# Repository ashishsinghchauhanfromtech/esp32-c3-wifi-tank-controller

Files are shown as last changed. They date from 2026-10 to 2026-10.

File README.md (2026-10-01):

# ESP32-C3 WiFi Tank Controller

### A 3D-Printed Robotics Prototype

A custom-built tank prototype combining **mechanical design, FDM 3D printing, embedded electronics, and wireless browser-based control**.

## Project Overview

The goal of this project was to design, manufacture, assemble, and control a compact motorized vehicle.

The mechanical structure includes a custom chassis, gears, wheels, belt components, and motor mounts designed using **Tinkercad** and fabricated using **FDM 3D printing**.

An **ESP32-C3 microcontroller** hosts a mobile-friendly control interface over its own Wi-Fi network, allowing independent control of two DC motors without requiring internet access.

---

## Mechanical Design & Manufacturing

* **CAD Software:** Tinkercad
* **Manufacturing Method:** FDM 3D Printing
* **Printer:** Creality Ender 3
* **Material:** PLA+
* **Nozzle:** 0.4 mm
* **Slicer:** Ultimaker Cura

### Custom-Designed Components

* **Chassis:** Structural platform for the vehicle.
* **Gears:** Mechanical transmission components.
* **Wheels:** Drive and ground-contact components.
* **Belt Components:** Experimental belt mechanism.
* **Motor Mounts:** Support and positioning for drive motors.
* **Electronic Cover:** Protective structure for electronics.
* **Charging/USB Mounts:** Access for charging and programming.

### Design-to-Prototype Workflow

1. Developed the mechanical components in Tinkercad.
2. Exported the models as STL files.
3. Prepared the parts for 3D printing using Ultimaker Cura.
4. Printed the components using a Creality Ender 3.
5. Assembled the printed mechanical components.
6. Integrated the motors, motor driver, battery system, and ESP32-C3.
7. Tested the assembled prototype and refined the design where required.

---

## Prototype Gallery

### 1. Assembled Tank Prototype

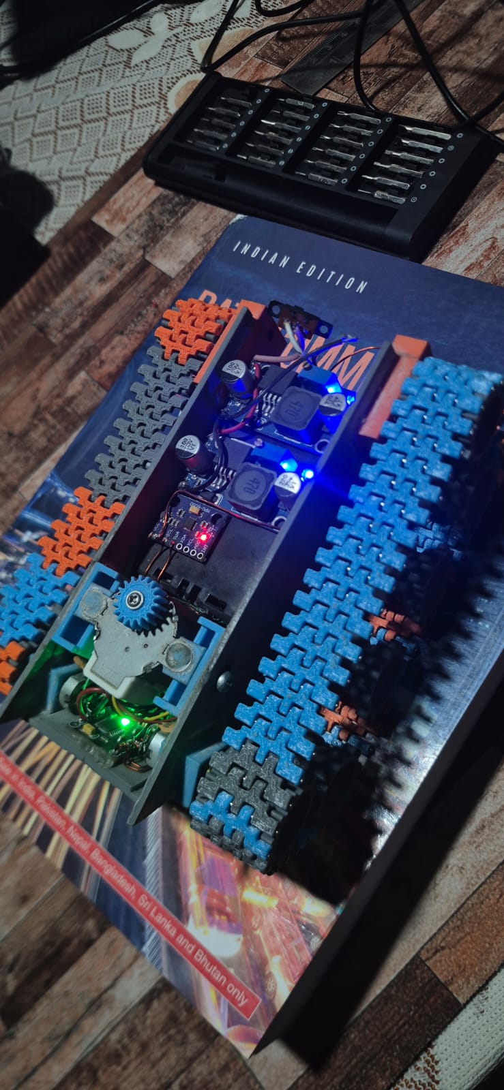
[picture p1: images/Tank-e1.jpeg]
Assembled tank prototype


### 2. Chassis Development

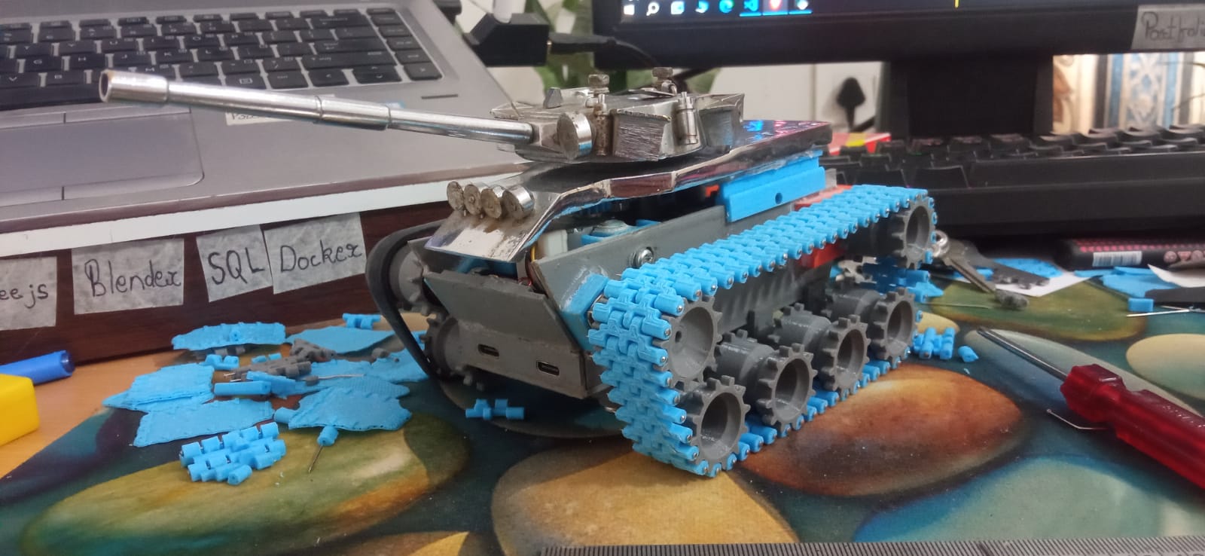
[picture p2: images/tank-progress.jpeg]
Chassis development


### 3. Electronics and Wiring

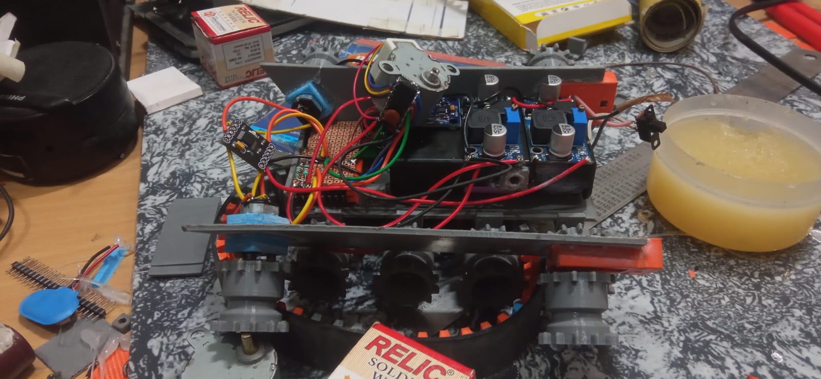
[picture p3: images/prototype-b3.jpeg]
Electronics and wiring


### 4. Mechanical Assembly

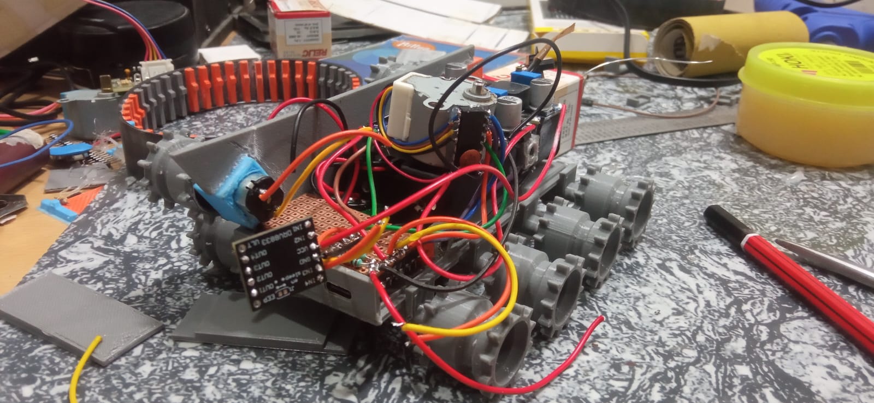
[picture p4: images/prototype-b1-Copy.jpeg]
Mechanical assembly


### 5. Prototype Development

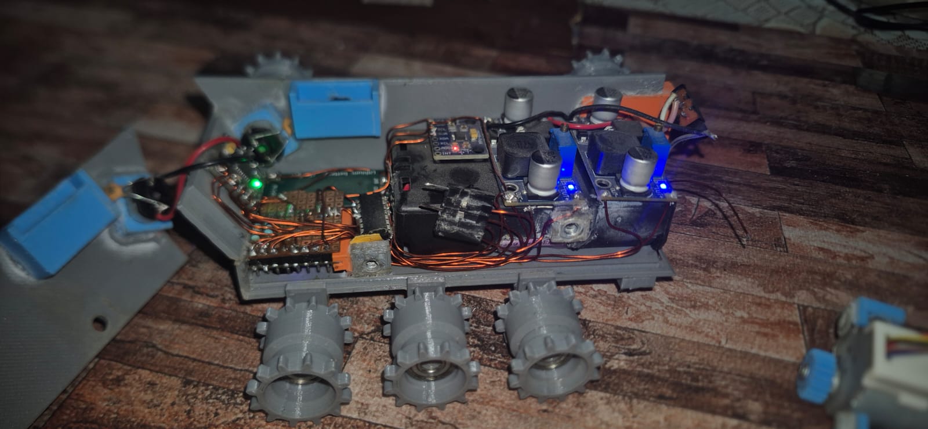
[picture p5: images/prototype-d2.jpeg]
Prototype development


### 6. Motor and Gear System

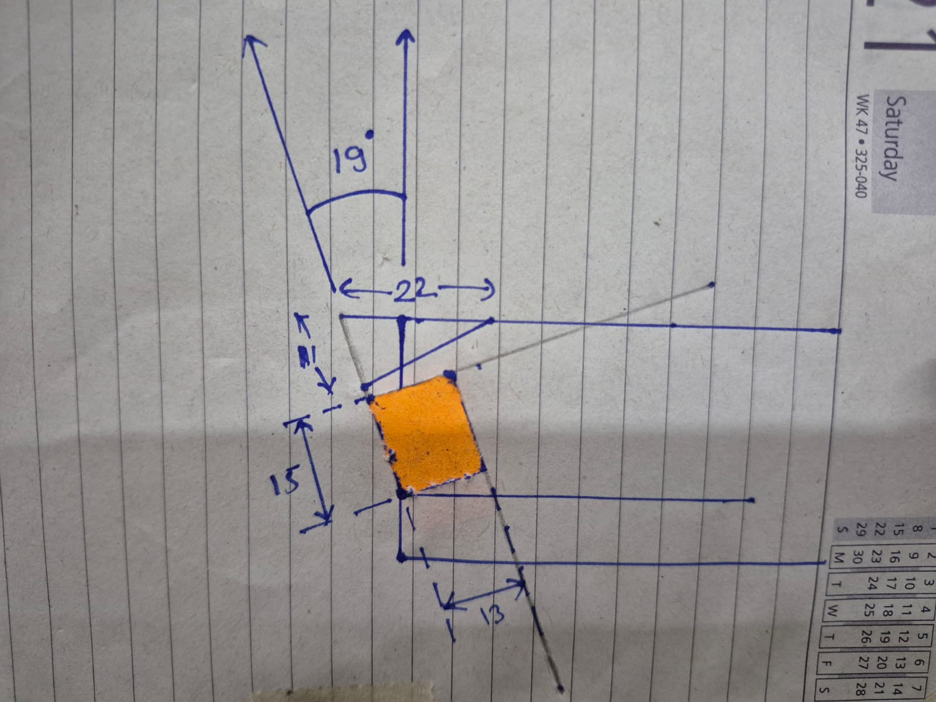
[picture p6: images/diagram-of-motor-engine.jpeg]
Motor and gear system


### Chassis and Wheel Development

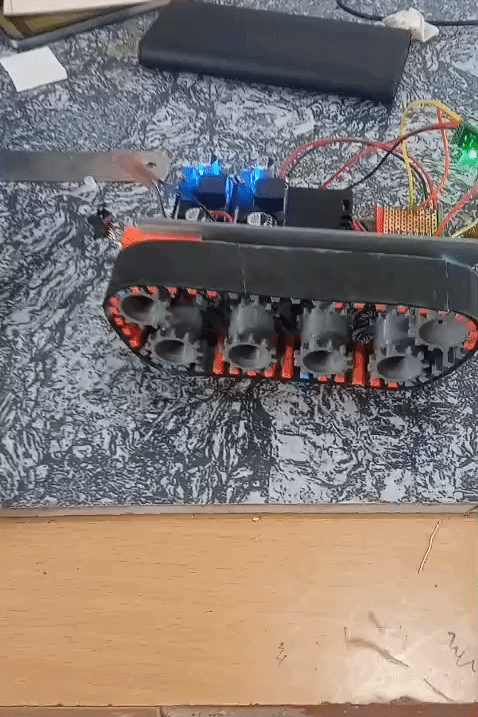
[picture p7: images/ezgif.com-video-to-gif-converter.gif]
Chassis and Wheel Development


### 8. 3D-Printed Wheel

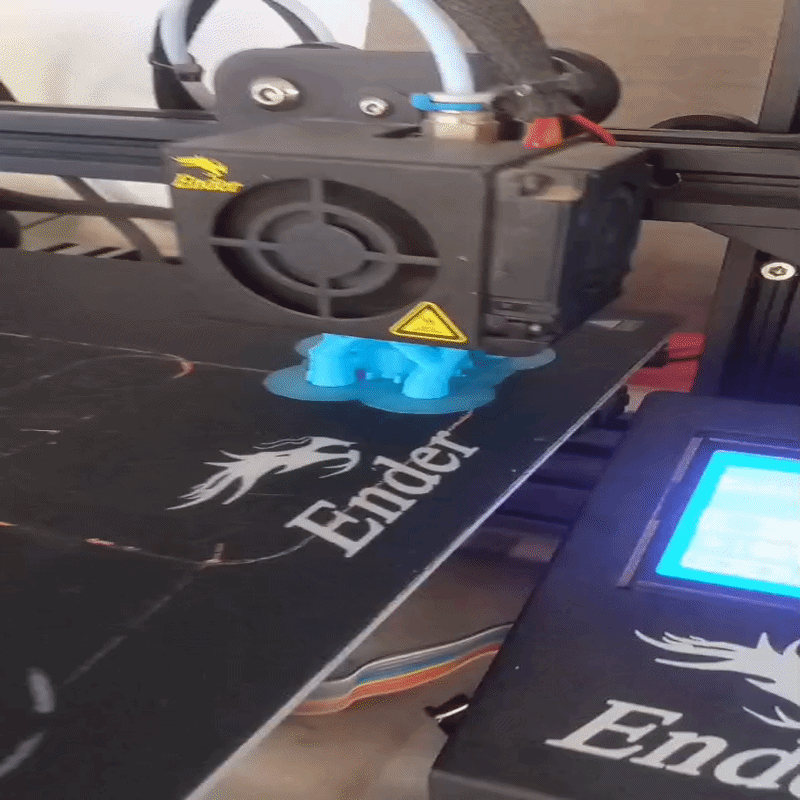
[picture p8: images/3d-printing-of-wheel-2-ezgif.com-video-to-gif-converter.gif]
3D printed wheel


### 9. Belt Prototype

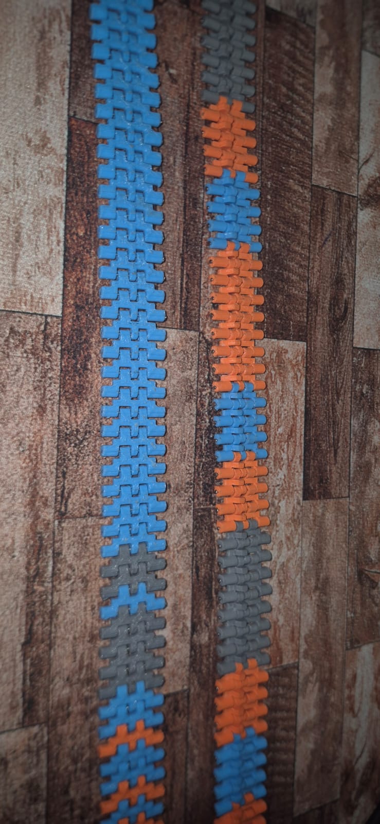
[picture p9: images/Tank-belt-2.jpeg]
Belt prototype


### 10. Wheel Prototype

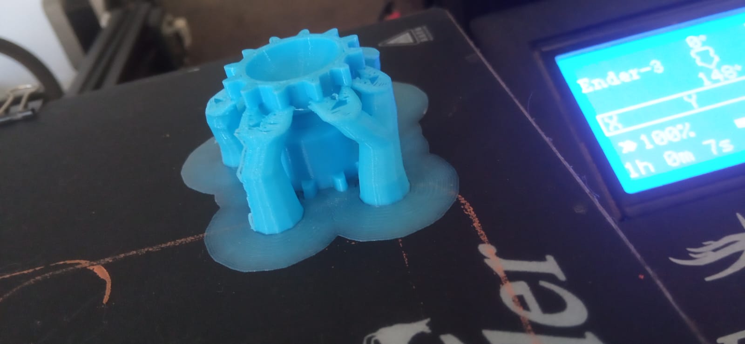
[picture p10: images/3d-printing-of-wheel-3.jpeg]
Wheel prototype


---

## Electronics & Control

### Main Components

* ESP32-C3 Development Board
* DRV8833 Dual Motor Driver
* Two DC Gear Motors
* Battery System
* Voltage Regulation
* Wi-Fi Access Point
* LittleFS Storage

### Motor Control Features

* Independent left and right motor control
* Variable motor speed using PWM
* Forward and reverse movement
* Automatic motor stop
* Automatic control centering
* Wireless operation without internet access

---

## Software

* Arduino / C++
* HTML
* CSS
* JavaScript
* PWM Motor Control
* ESP32-C3 Wi-Fi Access Point
* LittleFS

The web interface is stored on the ESP32-C3 using LittleFS, allowing the controller to operate without an external web server or internet connection.

---

## How It Works

1. The ESP32-C3 creates its own Wi-Fi network.
2. A phone or laptop connects to the ESP32-C3 network.
3. The user opens the controller webpage in a browser.
4. The webpage is served directly from the ESP32-C3.
5. Two independent controls operate the motors.
6. Motor speed changes according to the control position.
7. Releasing the controls stops the motors and returns the controls to neutral.

### System Architecture

```text
Phone / Laptop
       |
       | Wi-Fi
       v
 ESP32-C3 Access Point
       |
       +-- LittleFS Web Interface
       |
       v
   Motor Control
       |
       v
   DRV8833 Driver
      /       \
     v         v
  Motor A   Motor B
```

---

## Mechanical Design Considerations

The project involved several practical mechanical challenges during development, including:

* Gear fit and tolerance
* Gear durability
* Motor alignment
* Printed-part assembly
* Belt tension
* Wheel alignment
* Support removal
* Mechanical packaging
* Integration of electronics with the printed chassis

Some printed components required redesign and iteration to improve fit, strength, and assembly.

### 3D Printing Observations

During development, several practical printing issues were encountered:

* A gear fractured during support removal while the teeth remained intact.
* Some gear interfaces required tolerance adjustments.
* Stringing and warping were observed during some prints.
* Motor mount alignment required attention during assembly.
* Belt components required experimentation to achieve suitable tension.

These observations helped guide subsequent design iterations.

---

## 3D Models — STL Files

The following links point to 3D model files stored in this repository. They can be downloaded and opened using Cura, Tinkercad, or compatible 3D modeling software.

### Wheels and Gears

* [Ground Contact Gear Wheel — STL](https://github.com/ashishsinghchauhanfromtech/esp32-c3-wifi-tank-controller/blob/main/mechanical-design/GearWeels1-That-touches-the-ground-1-of-10-Total%5B12%5D.stl)

### Belt Components

* [Belt Prototype 1 — STL](https://github.com/ashishsinghchauhanfromtech/esp32-c3-wifi-tank-controller/blob/main/mechanical-design/belt-prototype-1.stl)
* [Belt Prototype 2 — STL](https://github.com/ashishsinghchauhanfromtech/esp32-c3-wifi-tank-controller/blob/main/mechanical-design/belt-prototype-2.stl)
* [Belt Tightening Wheel Gear Mount Mechanism — STL](https://github.com/ashishsinghchauhanfromtech/esp32-c3-wifi-tank-controller/blob/main/mechanical-design/Belt-tightning-wheel-gear-mount-mechanism.stl)

### Chassis Components

* [Chassis Top Electronic Safety — STL](https://github.com/ashishsinghchauhanfromtech/esp32-c3-wifi-tank-controller/blob/main/mechanical-design/Chassis-top-electronic-safety.stl)
* [Chassis Base with USB and Charging Indicator — STL](https://github.com/ashishsinghchauhanfromtech/esp32-c3-wifi-tank-controller/blob/main/mechanical-design/Chassis-Base-parallel-to-ground-with-usb-and-charging-indicat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)

### Charging and Programming

* [Type-C Ports for Charging and Code Uploading — STL](https://github.com/ashishsinghchauhanfromtech/esp32-c3-wifi-tank-controller/blob/main/mechanical-design/Type-c-Ports-for-charging-and-code-uploading.stl)

---

## Project Structure

```text
esp32-c3-wifi-tank-controller/
|
|-- README.md
|-- LICENSE
|
|-- firmware/
|   |-- tank.ino
|
|-- web-interface/
|   |-- index.html
|   |-- style.css
|   |-- js.js
|
|-- mechanical-design/
|   |-- *.stl
|   |-- 3d-printing-notes.md
|
|-- images/
|   |-- Tank-e1.jpeg
|   |-- tank-progress.jpg
|   |-- prototype-b3.jpg
|   |-- prototype-b1-Copy.jpg
|   |-- prototype-d2.jpg
|   |-- diagram-of-motor-engine.jpg
|   |-- prototype-c1.jpg
|   |-- 3d-printing-of-wheel-2.jpg
|   |-- Tank-belt-2.jpg
|   |-- 3d-printing-of-wheel-3.jpg
|
|-- hardware/
    |-- hardware documentation
```

---

## Project Status

**Functional prototype**

The project includes:

* 3D-printed mechanical components
* Custom Tinkercad designs
* Two DC motors
* DRV8833 motor driver
* ESP32-C3 wireless control
* Browser-based control interface
* Local Wi-Fi operation
* LittleFS-hosted web interface
* STL files for mechanical components

---

## Future Improvements

Potential future improvements include:

* Improved gear durability
* Optimized gear tolerances
* Improved belt mechanism
* More compact electronics mounting
* Improved motor alignment
* Reduced 3D-printing material usage
* Further chassis weight optimization
* Additional mechanical iterations

---

## License

The software and firmware in this project are released under the **MIT License**.

See the [LICENSE](LICENSE) file for details.

The 3D models and mechanical design files are included in the repository for reference and further development.

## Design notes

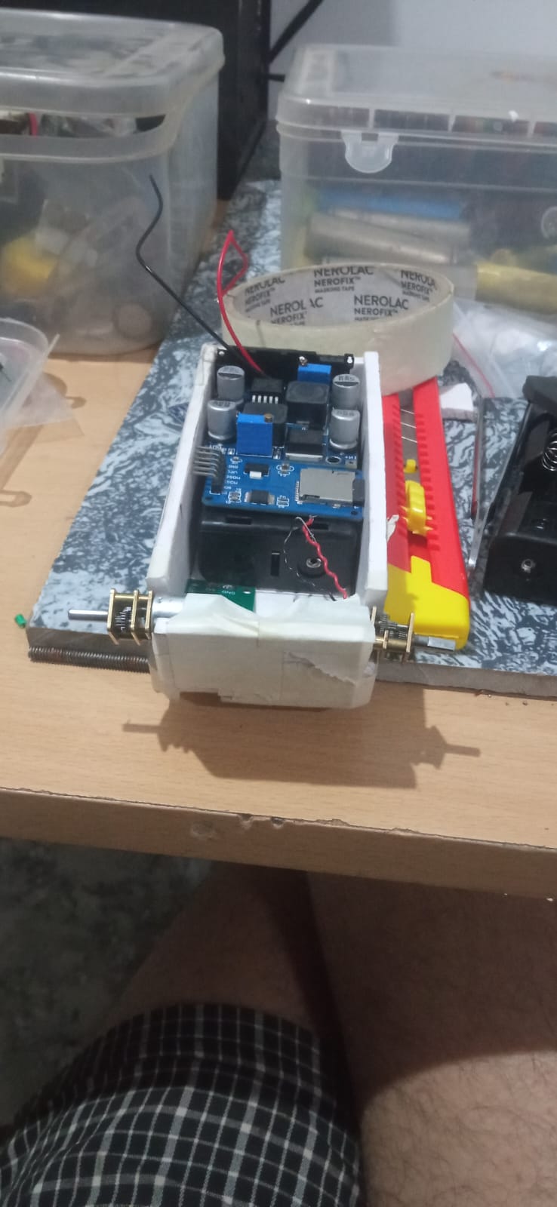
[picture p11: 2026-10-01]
images/prototype-a4.jpeg

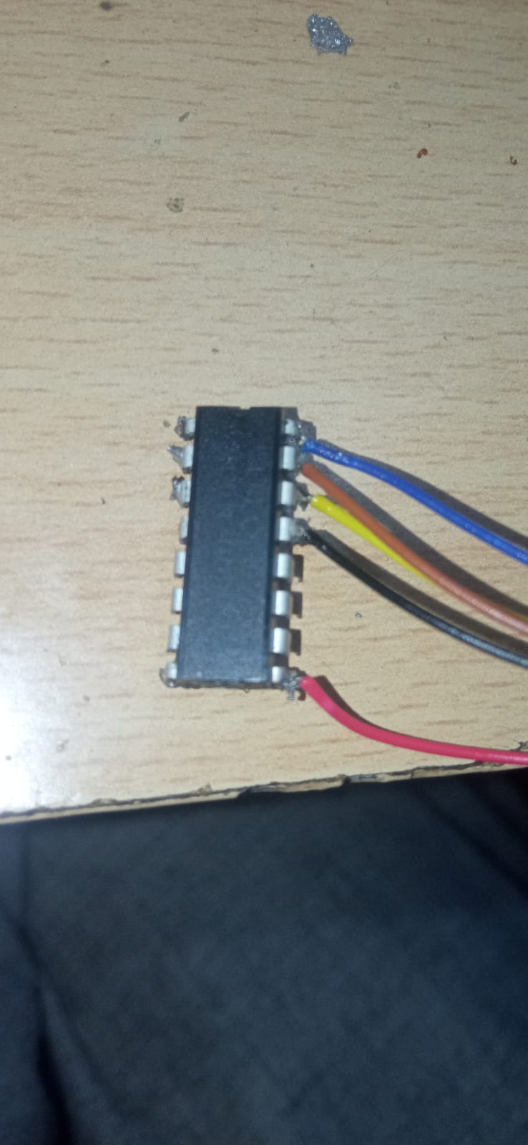
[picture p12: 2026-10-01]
images/ULN2003-Stapper-motor-driver-Copy.jpeg

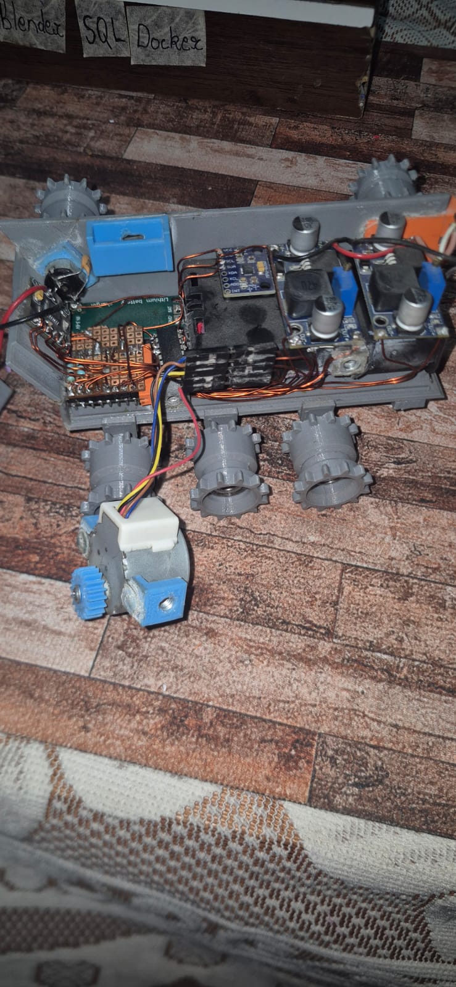
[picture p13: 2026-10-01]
images/Prototype-d6.jpeg

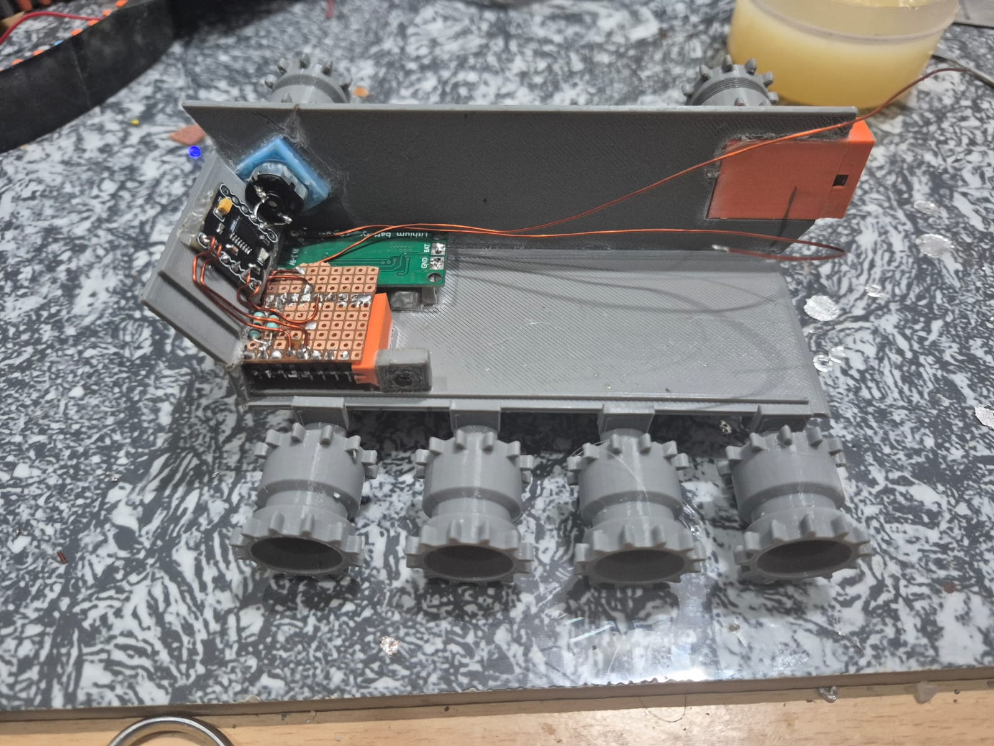
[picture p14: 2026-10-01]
images/motor-with-esp-Copy.jpeg

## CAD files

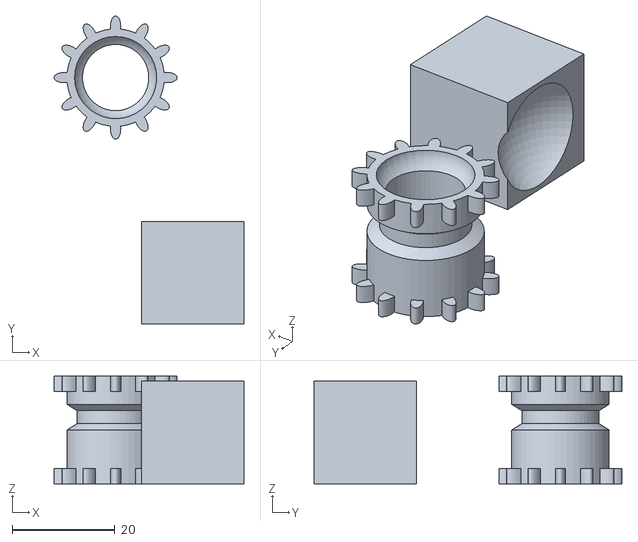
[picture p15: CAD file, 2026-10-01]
mechanical-design/GearWeels1-That-touches-the-ground-1-of-10-Total[12].stl
37.0 x 60.0 x 21.0

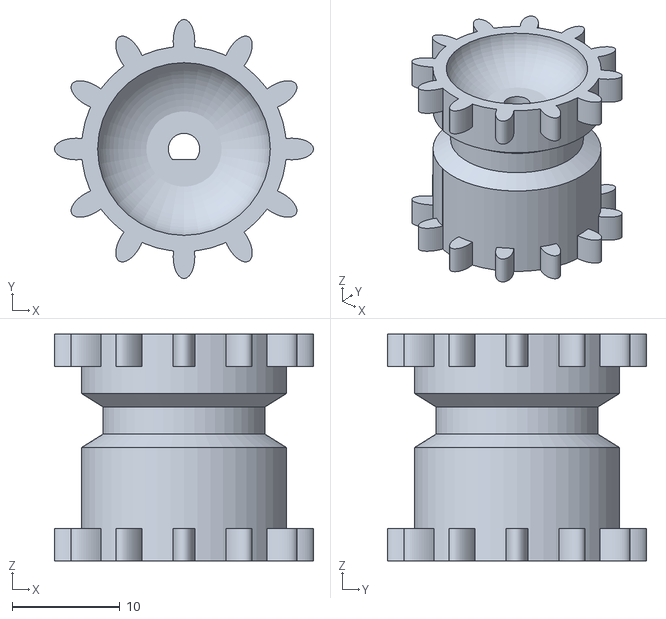
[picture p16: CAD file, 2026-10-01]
mechanical-design/GearWeels2-Connected-to-engine-1-of-2-total[12].stl
24.0 x 24.0 x 21.0

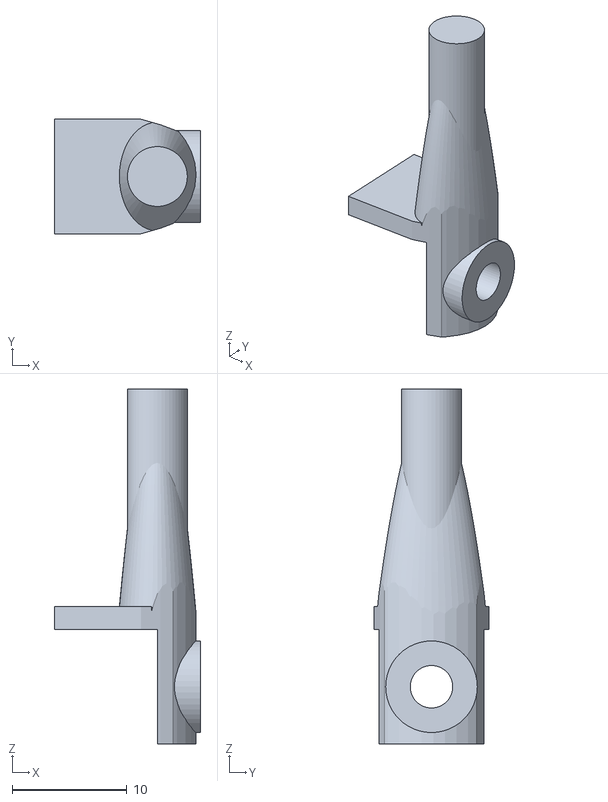
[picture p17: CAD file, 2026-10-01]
mechanical-design/connector-for-ground-wheels-to-the-chassis.stl
12.8 x 10.0 x 31.0

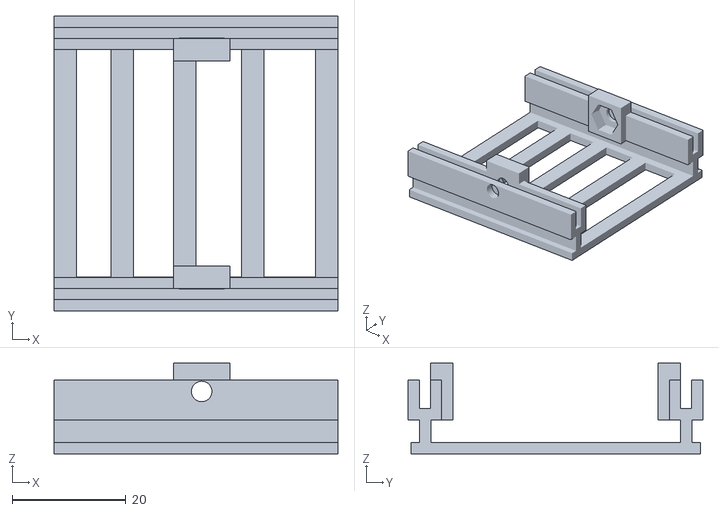
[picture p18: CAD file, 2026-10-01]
mechanical-design/Chassis-top-electronic-safety.stl
50.0 x 51.9 x 16.0

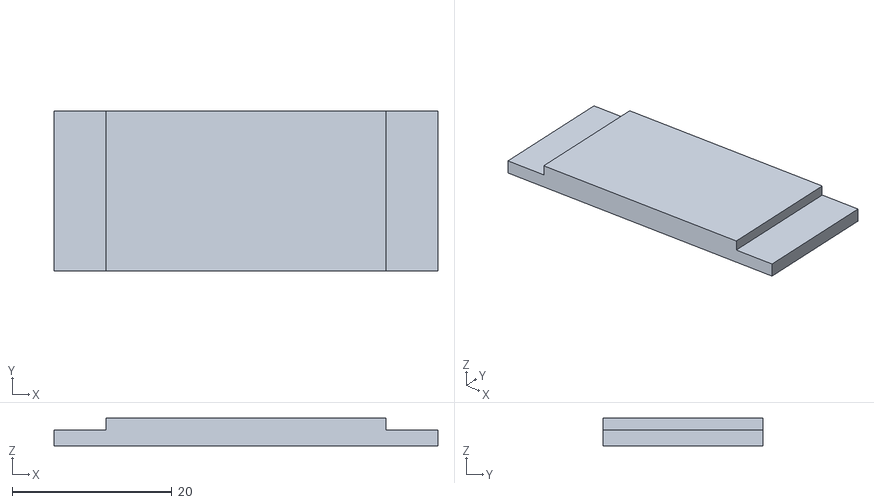
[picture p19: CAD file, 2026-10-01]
mechanical-design/Chassis-front-profile.stl
48.0 x 20.0 x 3.50

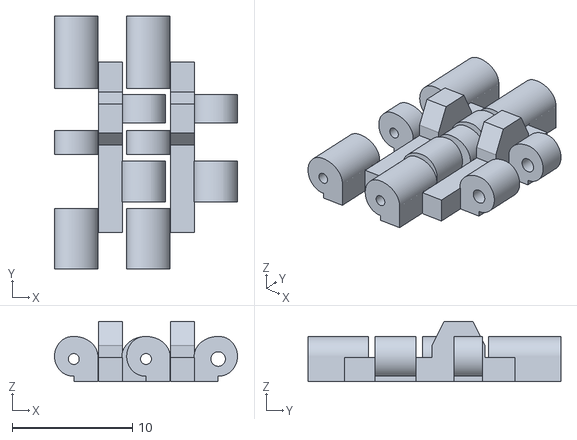
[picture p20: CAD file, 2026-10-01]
mechanical-design/belt-prototype-2.stl
15.2 x 21.0 x 5.00

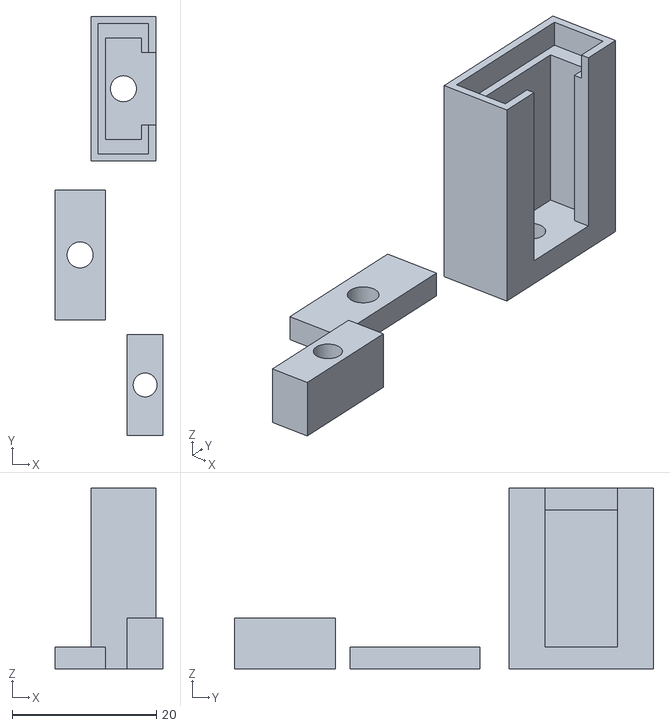
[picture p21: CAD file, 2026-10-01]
mechanical-design/Belt-tightning-wheel-gear-mount-mechanism.stl
15.0 x 58.0 x 25.0

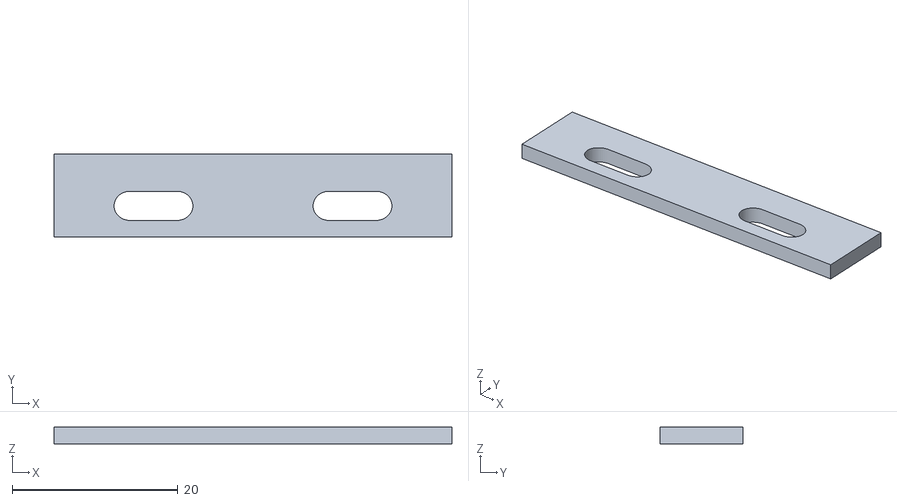
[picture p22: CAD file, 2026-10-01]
mechanical-design/Type-c-Ports-for-charging-and-code-uploading.stl
48.0 x 10.0 x 2.00

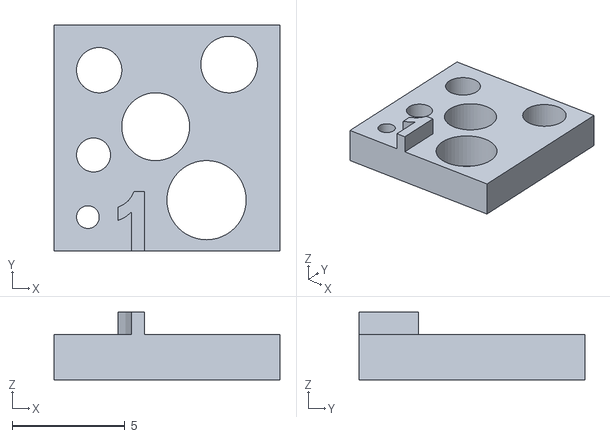
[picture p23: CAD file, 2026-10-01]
mechanical-design/for-belt-mearurement.stl
10.0 x 10.0 x 3.00

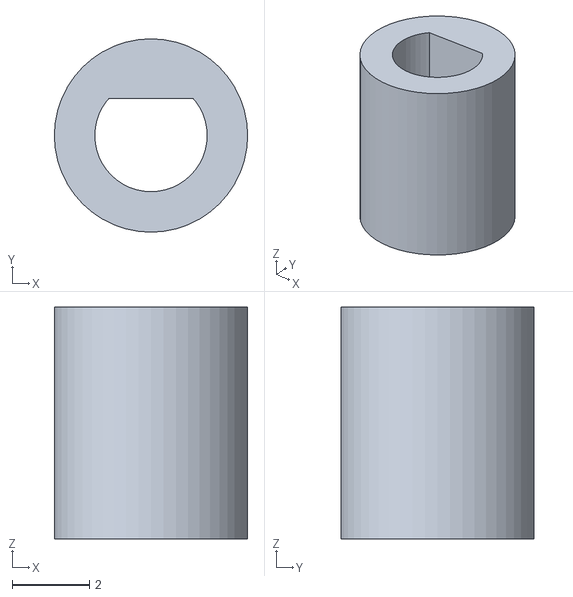
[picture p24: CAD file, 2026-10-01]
mechanical-design/Engine-motor-shaft-measurement.stl
5.00 x 5.00 x 6.00

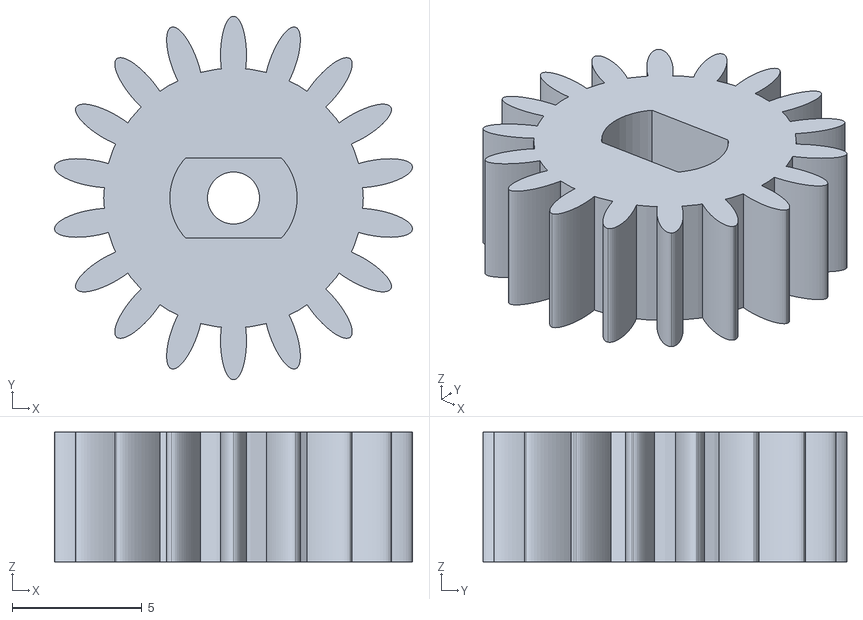
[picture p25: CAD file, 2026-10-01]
mechanical-design/tank-nozel-motor-gear1.stl
13.8 x 14.0 x 5.00

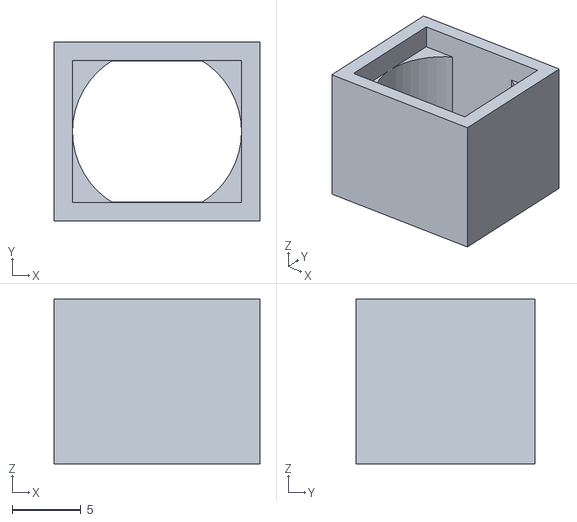
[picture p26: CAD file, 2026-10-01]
mechanical-design/Engine-motor-lower-mount.stl
15.0 x 13.0 x 12.0

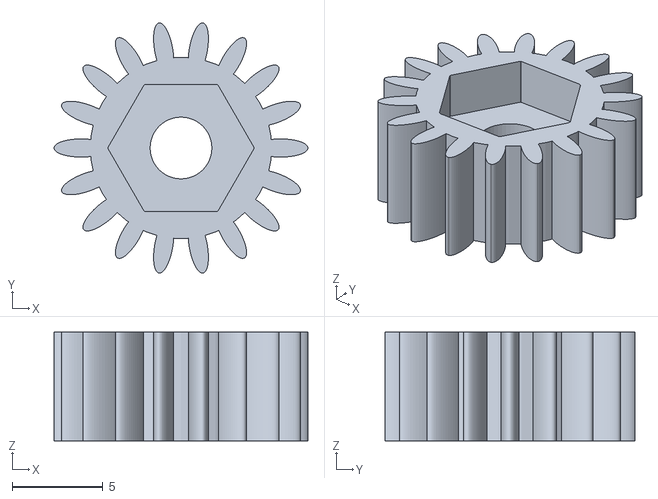
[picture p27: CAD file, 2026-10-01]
mechanical-design/tank-nozel-motor-gear2.stl
14.0 x 13.8 x 6.00

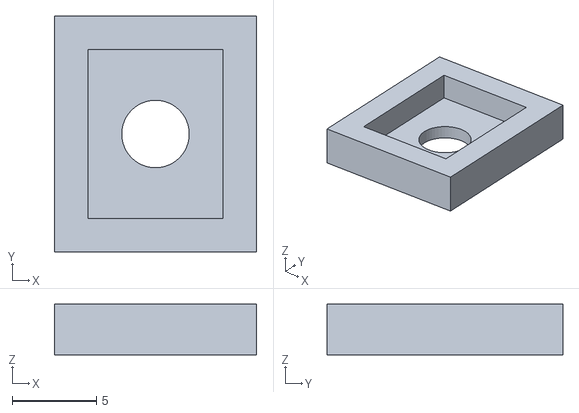
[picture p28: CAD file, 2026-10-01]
mechanical-design/Engine-motor-top-mount.stl
12.0 x 14.0 x 3.00

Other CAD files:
mechanical-design/tank-nozel-motor-top-mount.stl
mechanical-design/Chassis-Base-parallel-to-ground-with-usb-and-charging-indicator.stl
mechanical-design/esp32-c3-mount.stl
mechanical-design/Chassis-side-profile-for-belttightningwheels-groundwheels-enginewheels.stl
mechanical-design/Tank-nozel-motor-mount-on-top.stl
mechanical-design/belt-prototype-1.stl

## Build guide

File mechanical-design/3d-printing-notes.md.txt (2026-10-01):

# 3D Printing & Manufacturing Notes

## Project
**ESP32-C3 WiFi Tank Controller — Mechanical Prototype**

## 1. Manufacturing Overview

The mechanical components of this tank prototype were designed in Tinkercad and fabricated using FDM (Fused Deposition Modeling) 3D printing.

The printed components include:
- Chassis
- Gears
- Motor mounts

The objective was to create a functional mechanical structure capable of supporting the drive system and integrating with the electronic control hardware.

## 2. Equipment and Materials

| Parameter | Specification |
|---|---|
| 3D Printer | Creality Ender 3 |
| Slicing Software | Ultimaker Cura |
| Printing Technology | FDM / FFF |
| Material | PLA+ |
| Nozzle Diameter | 0.4 mm |
| Layer Height | Not specified |
| Infill Density | 100% |
| Wall Settings | Not specified |
| CAD Software | Tinkercad |
| Export Format | STL |

*Note: Layer height and wall settings are unspecified because the exact values have not been confirmed.*

## 3. Design-to-Manufacturing Workflow

### Step 1 — CAD Modeling
Created the chassis, gears, and motor mounts using Tinkercad. The models were intended to provide structural support, motor mounting, and mechanical drive functionality.

### Step 2 — STL Export
Exported the designed components into STL format for preparation in the slicing software.

### Step 3 — Slicing and Print Preparation
Imported the STL models into Ultimaker Cura and prepared the components for fabrication on the Creality Ender 3.

The confirmed infill density was 100%. Other slicing parameters, including layer height and wall settings, have not been documented.

### Step 4 — Fabrication
Manufactured the mechanical components using PLA+ filament and FDM 3D printing.

### Step 5 — Assembly and Integration
Assembled the printed chassis, gears, and motor mounts as part of the tank prototype. The mechanical structure was integrated with the DC motors and electronic control system.

### Step 6 — Fit and Functional Evaluation
Evaluated the printed components during assembly and prototype testing. Several issues were identified, as documented below.

## 4. Printing and Assembly Observations

### Gear Fracture During Support Removal
A gear fractured at its central region during support removal, while its teeth remained intact.

**Observation:** The component was vulnerable during post-processing.

**Potential areas for investigation:**
- Hub geometry and surrounding wall thickness
- Support placement and removal technique
- Part orientation during printing
- Material behavior and local stress concentration

**Possible future improvements:** Review the hub geometry, adjust support placement, and evaluate alternative orientations or stronger local geometry.

### Gear Fit and Tolerance
Gear engagement and fit presented tightness or looseness issues.

**Observation:** The fit between mating components required attention during assembly.

**Potential areas for investigation:**
- Gear dimensions and center distance
- Shaft and bore dimensions
- Manufacturing tolerances
- Printer dimensional accuracy

**Possible future improvements:** Use small test prints to evaluate clearances before manufacturing the complete set of components.

### Stringing or Warping
Stringing or warping was observed during printing.

**Potential areas for investigation:**
- Retraction settings
- Nozzle and bed temperatures
- Bed adhesion
- Cooling settings
- Filament condition and storage

**Possible future improvements:** Calibrate retraction, verify material-specific temperature recommendations, and review bed preparation and first-layer adhesion.

### Motor Mount Alignment
Motor mounting alignment presented an issue during assembly.

**Observation:** The relationship between the mounting geometry and the motor position required attention.

**Potential areas for investigation:**
- Mounting-hole dimensions
- Motor seating surfaces
- Shaft alignment
- Clearance between the motor, gears, and chassis

**Possible future improvements:** Refine mounting geometry and validate alignment using a small test print before printing revised full-size parts.

*The potential causes and improvements listed above are design considerations for future iterations, not confirmed root causes or completed modifications.*

## 5. Design Considerations for Future Iterations

Potential areas for refinement include:

- Improving gear hub strength and resistance to handling damage
- Refining gear clearances and shaft fit
- Improving motor mounting alignment
- Reducing printing defects through slicer calibration
- Reviewing support placement for easier post-processing
- Evaluating material usage and structural requirements
- Improving assembly access and maintainability

Any revised geometry or print settings should be validated through physical testing.

## 6. Documentation and Reproducibility

The project repository includes, or is intended to include:

- Tinkercad-designed component exports in STL format
- Prototype photographs
- ESP32-C3 firmware
- Browser-based motor control interface
- Hardware and assembly documentation

Exact layer height, wall settings, printing temperatures, print speeds, and support parameters have not been recorded in this document.

## 7. Project Outcome

The 3D-printed chassis, gears, and motor mounts form the mechanical structure of the ESP32-C3 WiFi Tank Controller prototype.

The fabrication and assembly process provided practical experience with CAD-to-STL preparation, FDM manufacturing, component fit, support removal, motor mounting, and mechanical integration with embedded electronics.

The identified issues provide concrete starting points for further design refinement and prototype testing.

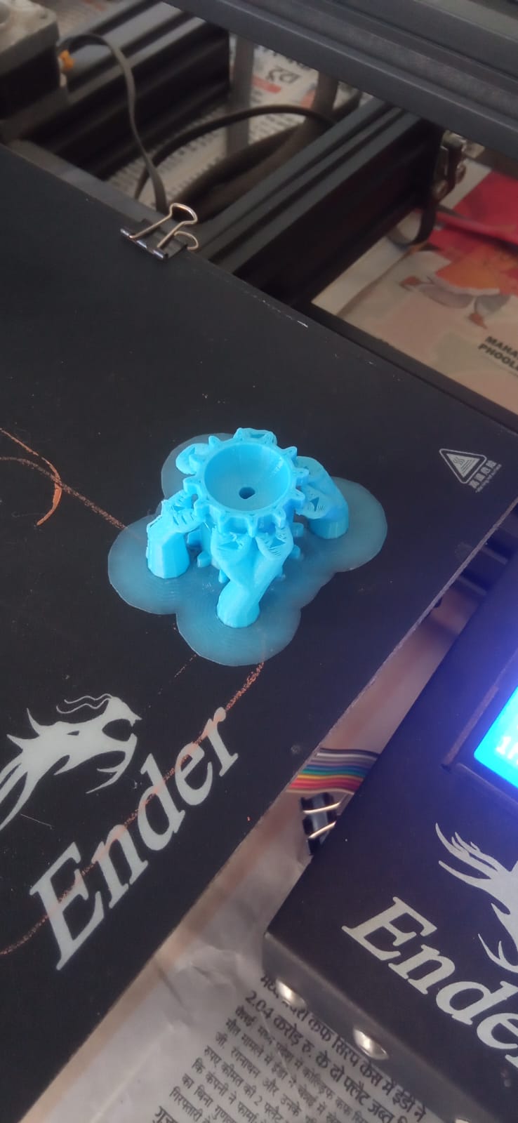
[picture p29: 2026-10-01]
images/3d-printing-of-wheel-4.jpeg

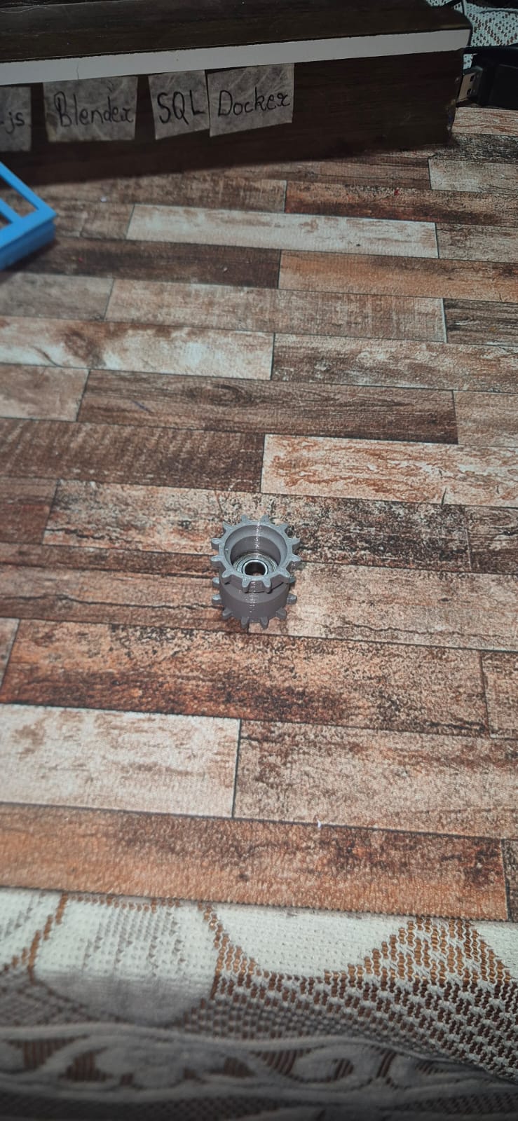
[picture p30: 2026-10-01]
images/printed-wheel.jpeg

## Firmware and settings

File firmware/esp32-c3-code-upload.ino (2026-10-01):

#include <WiFi.h>
#include <WebServer.h>
#include <LittleFS.h>


// ============ MOTOR PINS ============

#define AIN1 3
#define AIN2 4

#define BIN1 8
#define BIN2 9



// ============ PWM SETTINGS ============

#define PWM_FREQ 20000
#define PWM_RES 8

#define MIN_PWM 50



// ============ WIFI ============

const char* ssid = "  ";//Name of your esp32c3
const char* password = "";//Password of esp32c3


WebServer server(80);



// ============ FUNCTIONS ============

void motorAForward();
void motorAReverse();
void motorAStop();

void motorBForward();
void motorBReverse();
void motorBStop();

int mapSpeed(int s);



// ================= SETUP =================

void setup()
{

  Serial.begin(115200);

  delay(1000);



  // -------- LittleFS --------

  if(!LittleFS.begin())
  {
    Serial.println("LittleFS Failed");
    return;
  }

  Serial.println("LittleFS Ready");




  // -------- Motor pins --------

  pinMode(AIN1, OUTPUT);
  pinMode(AIN2, OUTPUT);

  pinMode(BIN1, OUTPUT);
  pinMode(BIN2, OUTPUT);



  digitalWrite(AIN1, LOW);
  digitalWrite(AIN2, LOW);

  digitalWrite(BIN1, LOW);
  digitalWrite(BIN2, LOW);



  // -------- ESP32-C3 PWM --------

  ledcAttach(
    AIN1,
    PWM_FREQ,
    PWM_RES
  );


  ledcAttach(
    AIN2,
    PWM_FREQ,
    PWM_RES
  );


  ledcAttach(
    BIN1,
    PWM_FREQ,
    PWM_RES
  );


  ledcAttach(
    BIN2,
    PWM_FREQ,
    PWM_RES
  );



  // -------- WiFi AP --------

  WiFi.mode(WIFI_AP);

  WiFi.softAP(
    ssid,
    password
  );


  Serial.println("WiFi Started");

  Serial.print("IP Address: ");

  Serial.println(
    WiFi.softAPIP()
  );




  // ============ MOTOR ROUTES ============


  server.on(
    "/a/fwd",
    motorAForward
  );


  server.on(
    "/a/rev",
    motorAReverse
  );


  server.on(
    "/a/stop",
    motorAStop
  );



  server.on(
    "/b/fwd",
    motorBForward
  );


  server.on(
    "/b/rev",
    motorBReverse
  );


  server.on(
    "/b/stop",
    motorBStop
  );




  // ============ WEBSITE ============


  server.on(
    "/",
    []()
    {
      File file =
      LittleFS.open(
        "/index.html",
        "r"
      );

      server.streamFile(
        file,
        "text/html"
      );

      file.close();
    }
  );



  server.on(
    "/style.css",
    []()
    {
      File file =
      LittleFS.open(
        "/style.css",
        "r"
      );

      server.streamFile(
        file,
        "text/css"
      );

      file.close();
    }
  );



  server.on(
    "/js.js",
    []()
    {
      File file =
      LittleFS.open(
        "/js.js",
        "r"
      );

      server.streamFile(
        file,
        "application/javascript"
      );

      file.close();
    }
  );



  server.begin();


  Serial.println("Server Started");

}



// ================= LOOP =================


void loop()
{
  server.handleClient();
}






// ================= SPEED MAP =================


int mapSpeed(int s)
{

  s = constrain(
    s,
    0,
    255
  );


  return map(
    s,
    0,
    255,
    MIN_PWM,
    255
  );

}







// ================= MOTOR A =================



void motorAForward()
{

  int s =
  mapSpeed(
    server.arg("s").toInt()
  );


  digitalWrite(
    AIN2,
    LOW
  );


  ledcWrite(
    AIN1,
    s
  );


  server.send(
    200,
    "text/plain",
    "A FORWARD"
  );

}





void motorAReverse()
{

  int s =
  mapSpeed(
    server.arg("s").toInt()
  );


  digitalWrite(
    AIN1,
    LOW
  );


  ledcWrite(
    AIN2,
    s
  );


  server.send(
    200,
    "text/plain",
    "A REVERSE"
  );

}





void motorAStop()
{

  ledcWrite(
    AIN1,
    0
  );


  ledcWrite(
    AIN2,
    0
  );


  digitalWrite(
    AIN1,
    LOW
  );


  digitalWrite(
    AIN2,
    LOW
  );


  server.send(
    200,
    "text/plain",
    "A STOP"
  );

}








// ================= MOTOR B =================



void motorBForward()
{

  int s =
  mapSpeed(
    server.arg("s").toInt()
  );


  digitalWrite(
    BIN2,
    LOW
  );


  ledcWrite(
    BIN1,
    s
  );


  server.send(
    200,
    "text/plain",
    "B FORWARD"
  );

}





void motorBReverse()
{

  int s =
  mapSpeed(
    server.arg("s").toInt()
  );


  digitalWrite(
    BIN1,
    LOW
  );


  ledcWrite(
    BIN2,
    s
  );


  server.send(
    200,
    "text/plain",
    "B REVERSE"
  );

}





void motorBStop()
{

  ledcWrite(
    BIN1,
    0
  );


  ledcWrite(
    BIN2,
    0
  );


  digitalWrite(
    BIN1,
    LOW
  );


  digitalWrite(
    BIN2,
    LOW
  );


  server.send(
    200,
    "text/plain",
    "B STOP"
  );

}
